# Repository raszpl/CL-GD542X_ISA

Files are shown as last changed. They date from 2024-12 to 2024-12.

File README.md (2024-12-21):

Fork of https://github.com/matt1187/542x_ISA 'Remaking from Cirrus Logic Databook "CL-GD542X_Technical_Reference_Manual_Jan1994"' attempting to show some routing optimizations.

# Results

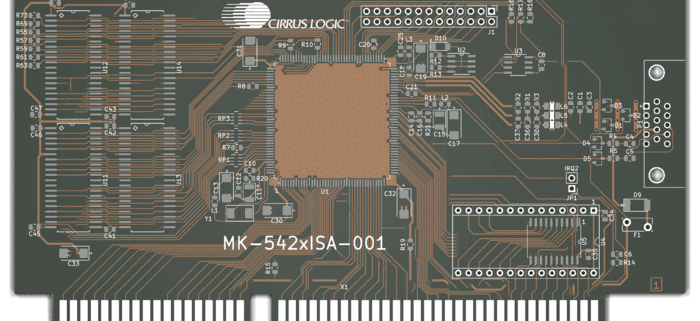
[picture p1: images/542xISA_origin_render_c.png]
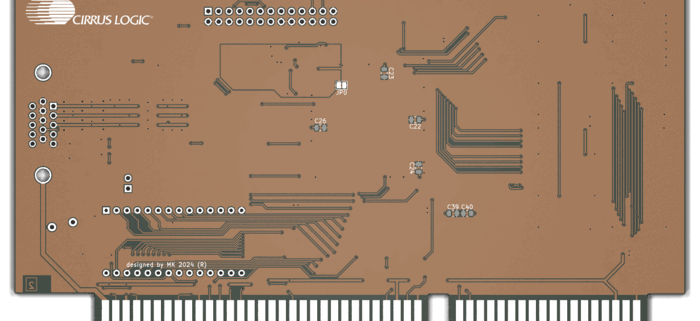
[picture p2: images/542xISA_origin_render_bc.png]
Original:[](/images/542xISA_origin_render.png?raw=true)[](/images/542xISA_origin_render_b.png?raw=true)

Optimisations, less and taking smaller area tracks you see on the back means better signal integrity.

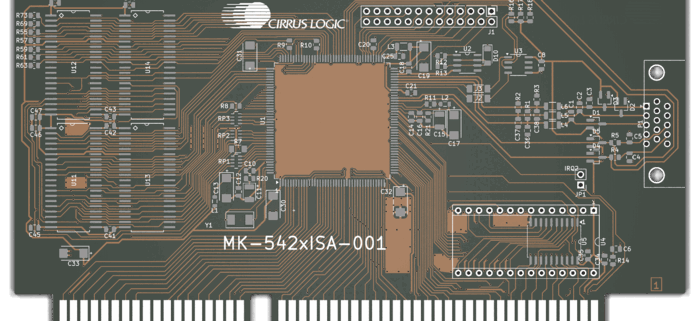
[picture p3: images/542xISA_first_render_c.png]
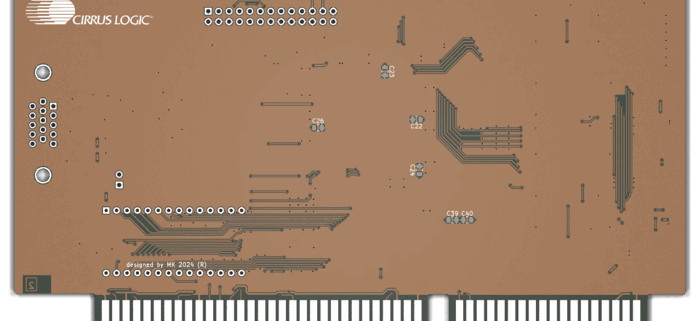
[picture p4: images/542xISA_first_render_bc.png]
Initial:[](/images/542xISA_first_render.png?raw=true)[](/images/542xISA_first_render_b.png?raw=true)

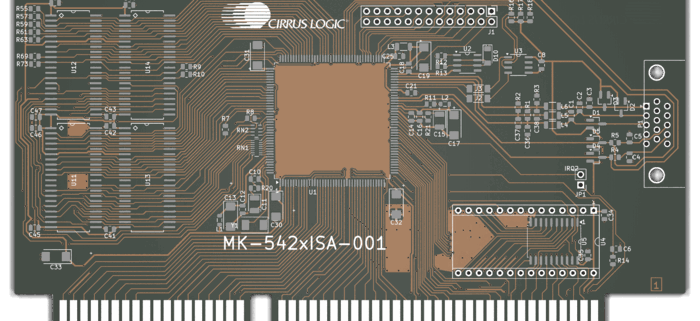
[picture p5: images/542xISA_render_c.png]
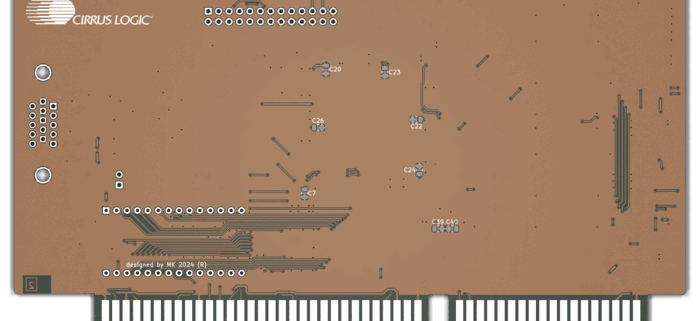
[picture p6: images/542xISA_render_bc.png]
Final:[](/images/542xISA_render.png?raw=true)[](/images/542xISA_render_b.png?raw=true)

Comparison between layouts: [Original](/images/original.png?raw=true), [Initial optimization](/images/first.png?raw=true), [Final version](/images/final.png?raw=true).

Black holes and red are cuts in ground plane, the smaller they are the better. Ideally you want one uninterrupted plane. Second bad but better than nothing option is ground island densely stitched on top of tracks forced to go into ground plane. Third bad option is as short as possible cuts to the ground plane and picking slow/steady (reset, VCC) signals as the ones going across, jumping across couple signals here and there is a lesser crime than slicing ground across half the PCB height. Fourth 'Im desperate here' option is crossing signals at 90 degree angle and hoping PCB thickness is enough. People in the eighties and early nineties didnt have it easy, nowadays similar size 4-layer PCBs are mere $20-30 for quick turnaround pototypes, with 6-layer not far behind at $40!

# Fixes

1 Bad ground. We dont want thin long ground noodles connected to real ground by a thin sliver on one side

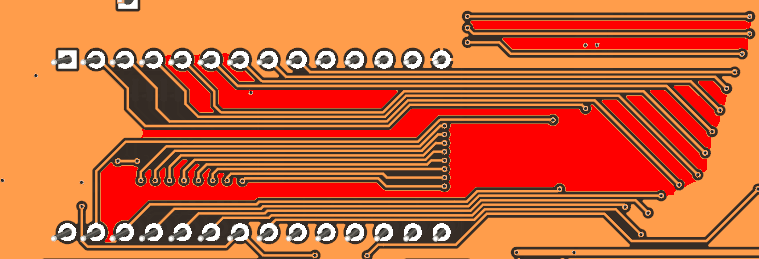
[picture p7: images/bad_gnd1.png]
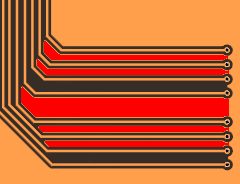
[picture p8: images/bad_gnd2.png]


like between:
- PD0 PD1 PD2 PD3 PD4 PD5 PD6
- PD16 20 21 22 23
- under U5
- tiny one under U11
- long big one under extended ISA slot
- A2_ISA 3 4 5 6 7

Ground that is not solid plane or densely (<wavelenght) stitched to solid plane no longer works as ground, it works like an antenna and amplifies interference. In the past guard traces were used before we had good modeling and understanding of magnetic propagation on the pcb, they only worked because putting one forced engineers to make more space between signal traces. All those dangling traces between signal tracks just resonate amplifying interference[^1].

3 Extended ISA slot - routing VCC straight to C33 instead of going across the card wouldnt be breaking ground plane under D8-16 and LA signals.

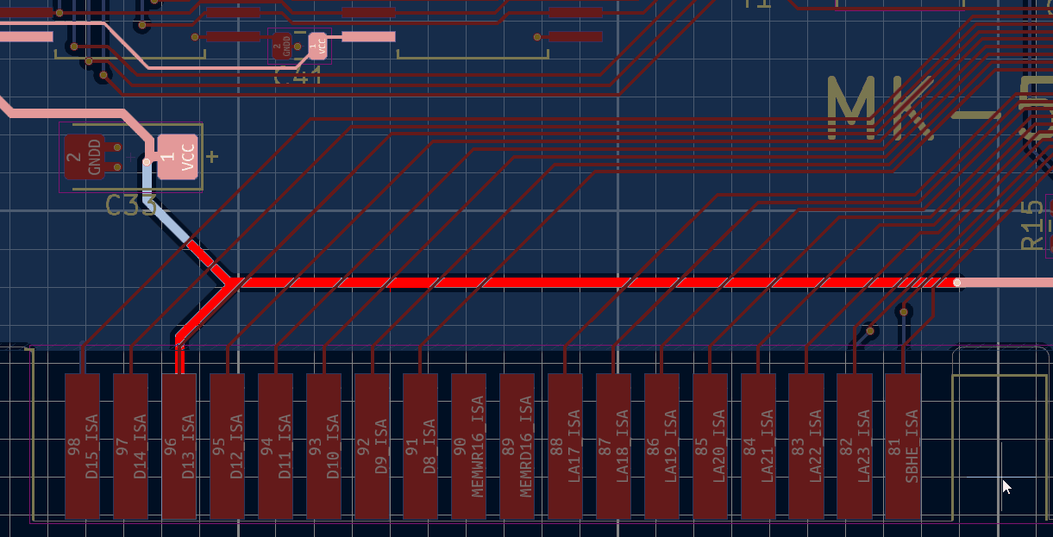
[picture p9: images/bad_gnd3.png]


4 Omitting ISA oscillator input option will make ground more solid. Currently it leaves a dangling track with very high frequency clock crossing D8-18 and LA lines while breaking ground even when unused. Using ISA 14MHz was a cost cutting measure saving maybe 50 cents for a crystal resonator and two capacitors in the nineties, nowadays useless.

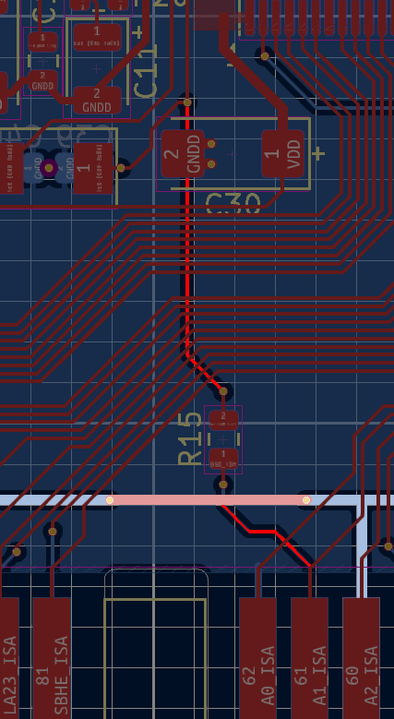
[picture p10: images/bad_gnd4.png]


5 Pin 159 oscillator goes in a weird around pad way making it go outside of ground plane coverage. Its especially critical to have uninterrupted ground under clock signals.

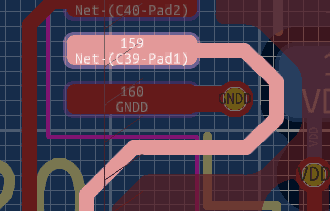
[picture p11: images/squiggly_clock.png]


6 Afaik separate isolated analog/digital ground planes is a relic of the past, modern techniques show it doesnt work if it cuts up ground into multiple islands and forces signals to cross them[^2][^3][^4]. Here for example it paradoxically messes with analog signal integrity by making RGB Video suddenly lose reference. Im fairly certain this aspect of Cirrus recommended design only makes things worse.

7 Optional EEprom pins also degrade analog RGB Video signals by breaking ground :( best option would be routing those two tracks with jumpers over analog RGB.

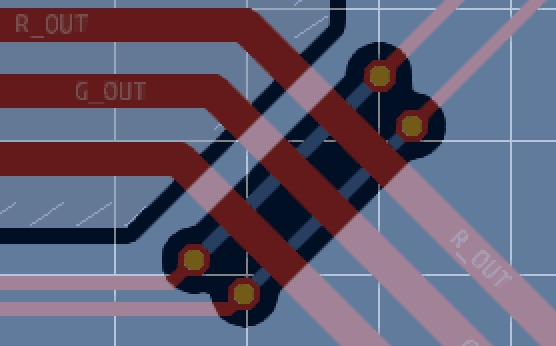
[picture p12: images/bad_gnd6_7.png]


8 Filtering analog VGA looks nice when symmetricaly placed in neat rows, but forces analog B crossing over analog G, and all analog tracks going under where they arent routed over ground plane. Vias high impedance is really bad for such high speed analog signals. Asymmetrical component placement might hurt OCD, but lets us leave Analog RGB on top layer over healthy uninterrupted ground.

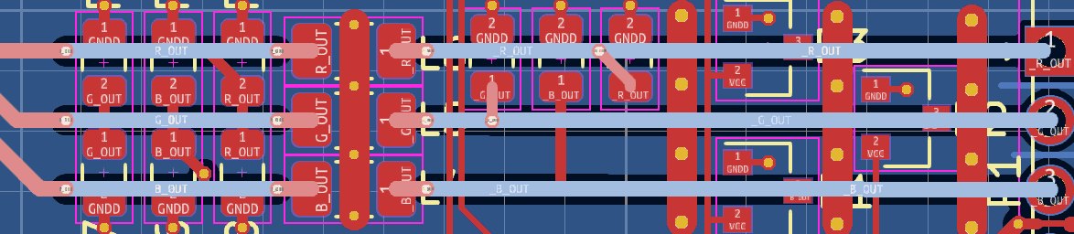
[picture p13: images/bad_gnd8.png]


9 H and V syncs cross each other with no ground underneath, swapping filtering sections around solves that.

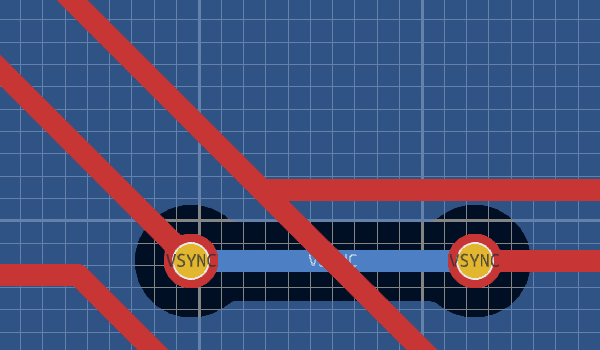
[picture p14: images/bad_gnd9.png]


10 3 amp fuse and thick tracks on Vga Pin 9 is overdoing it, especially considering Cirrus is not even capable of reading Edid. Removing altogether.

11 Very long RAS1 under U13 U14 can be avoided, makes it look stupid but ground plane is healthier = shorter cuts = shorter return paths = less interference and crosstalk.



TLDR Golden rule is every signal should run as close as possible (preferably over) a ground directly connecting source and destination of said signal with lowest impedance. Signals arent electrons, they are electromagnetic waves and need to close the loop. Closer the ground smaller the field, lower the ground impedance higher the frequency of mitigated interferences, bigger ground plane = better, traveling thru multiple vias = bad.

Some of the fixes are heavily overdoing it via stitched ground patches and are most likely also bad :) Nowadays upgrading from five PCBs with 2-layers to 4-layers of that size is $20, another $15 for 6-layer with ENIG finish, giving us infinitely healthier signal integrity and tons less routing work. __Please dont manufacture this!__ Other than for fun or experimentation there is very little sense manufacturing 2-layer design, repository is for educational purposes only.

# License
The project is free for non-commercial reproduction. Do not sell it on Ebay or other platforms for profit. Do not make a closed source derivative. Share your experiences and ideas with the community.

This work is licensed under a [Creative Commons Attribution-NonCommercial-ShareAlike 4.0 International License][cc-by-nc-sa].

[][cc-by-nc-sa]

[cc-by-nc-sa]: http://creativecommons.org/licenses/by-nc-sa/4.0/
[cc-by-nc-sa-image]: https://licensebuttons.net/l/by-nc-sa/4.0/88x31.png

# References
[^1]: https://resources.altium.com/p/guard-traces-hit-or-myth.
[^2]: https://resources.altium.com/p/how-to-use-a-star-point-for-analog-ground-digital-ground-connection
[^3]: https://resources.pcb.cadence.com/blog/2021-should-you-ever-separate-analog-and-digital-ground-planes
[^4]: "Ground planes in a PCB layout with 30 years of experience: The ultimate guide" by Hans Rosenberg https://www.youtube.com/watch?v=EEb_0dja8tE&list=PLsWHPs7La-3KUY2JDUyrz0Jc0xw8kH4zQ

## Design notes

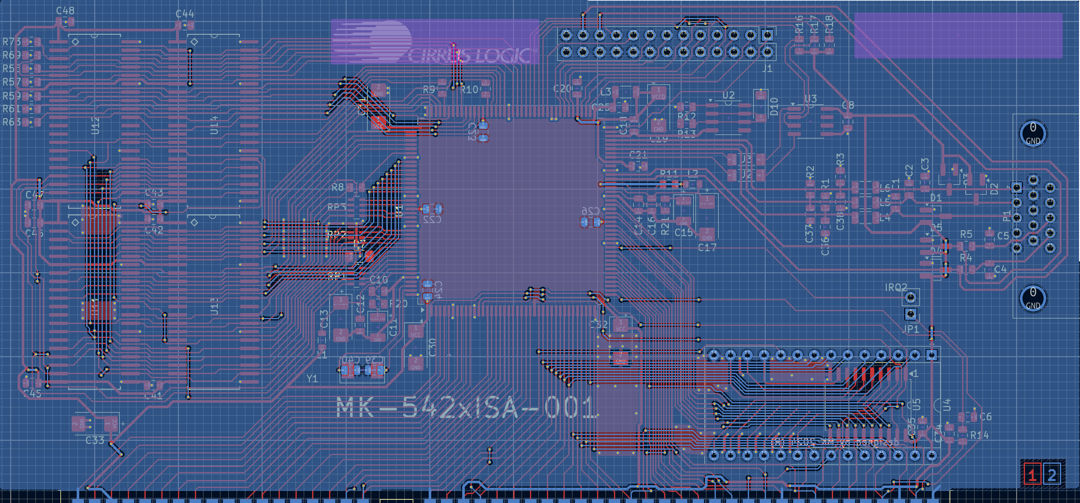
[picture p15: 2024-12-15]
images/first.png

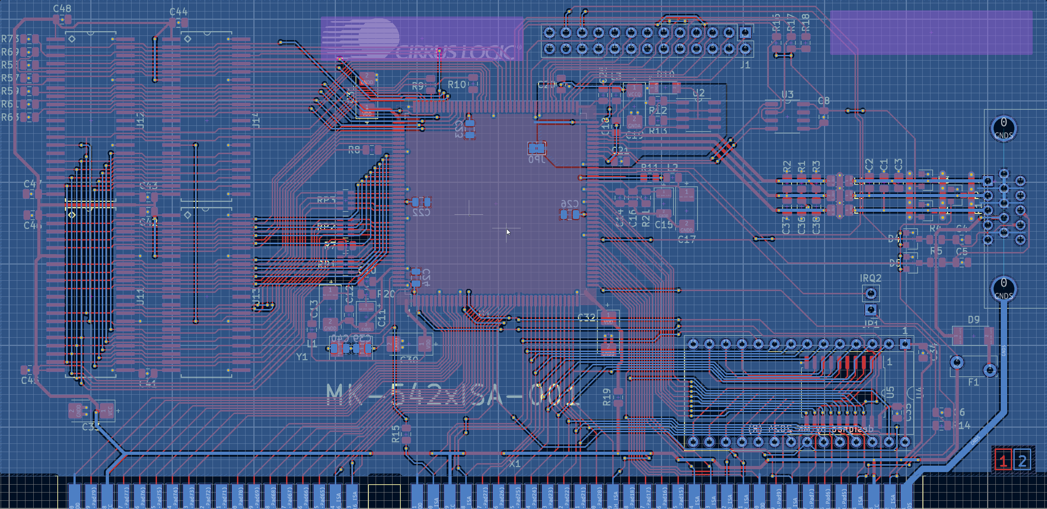
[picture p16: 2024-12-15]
images/original.png

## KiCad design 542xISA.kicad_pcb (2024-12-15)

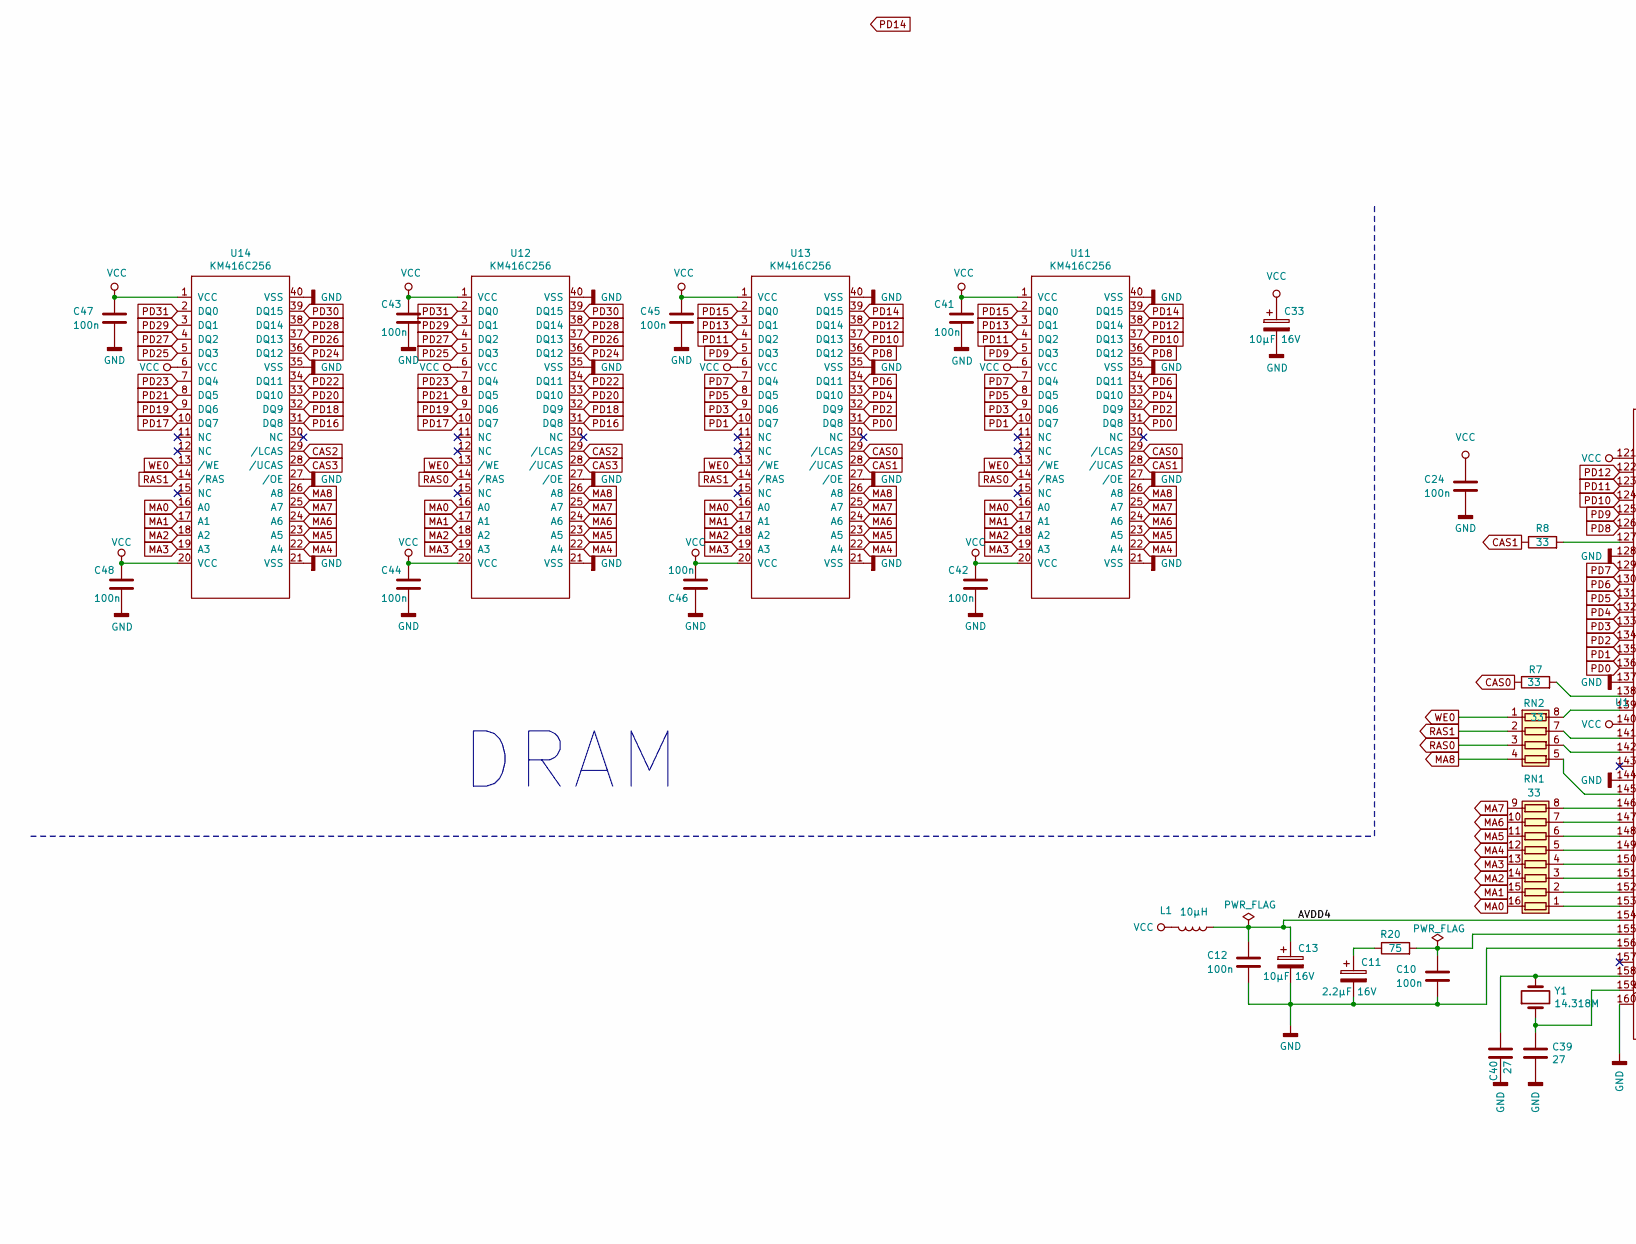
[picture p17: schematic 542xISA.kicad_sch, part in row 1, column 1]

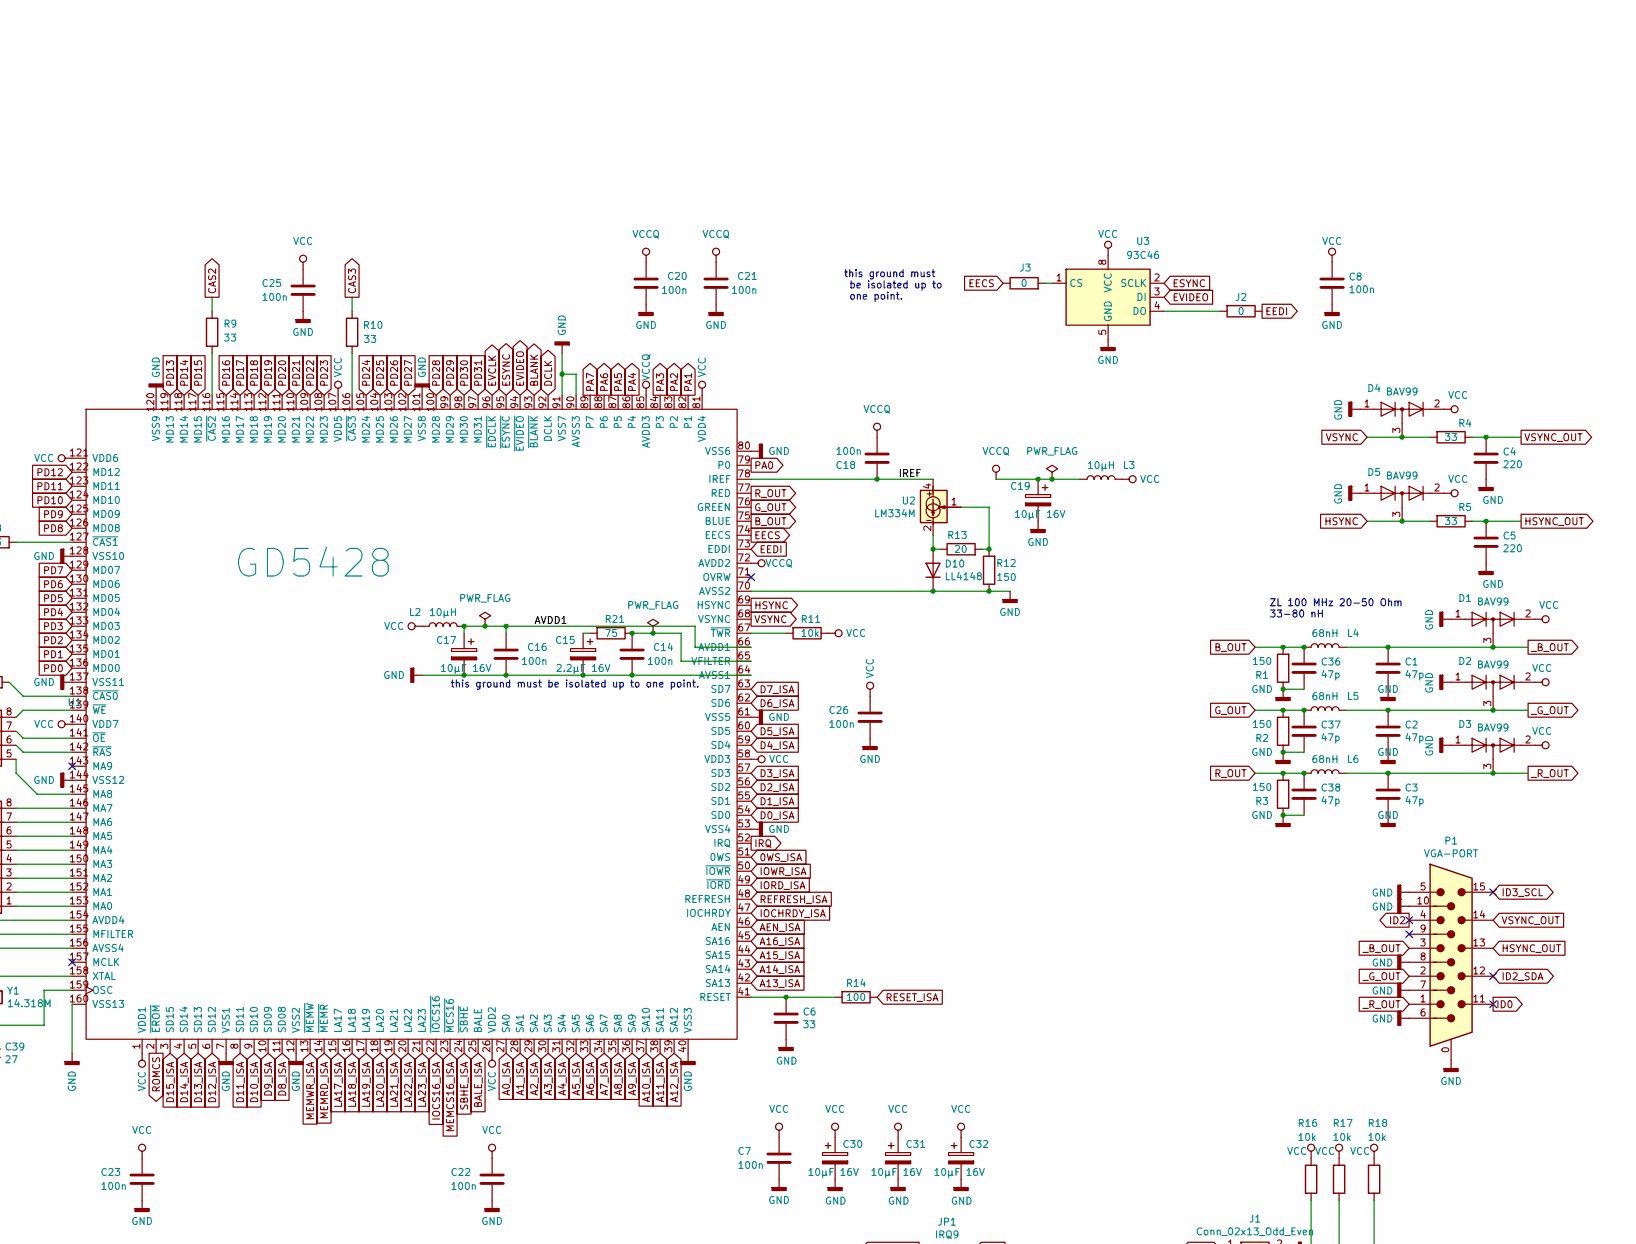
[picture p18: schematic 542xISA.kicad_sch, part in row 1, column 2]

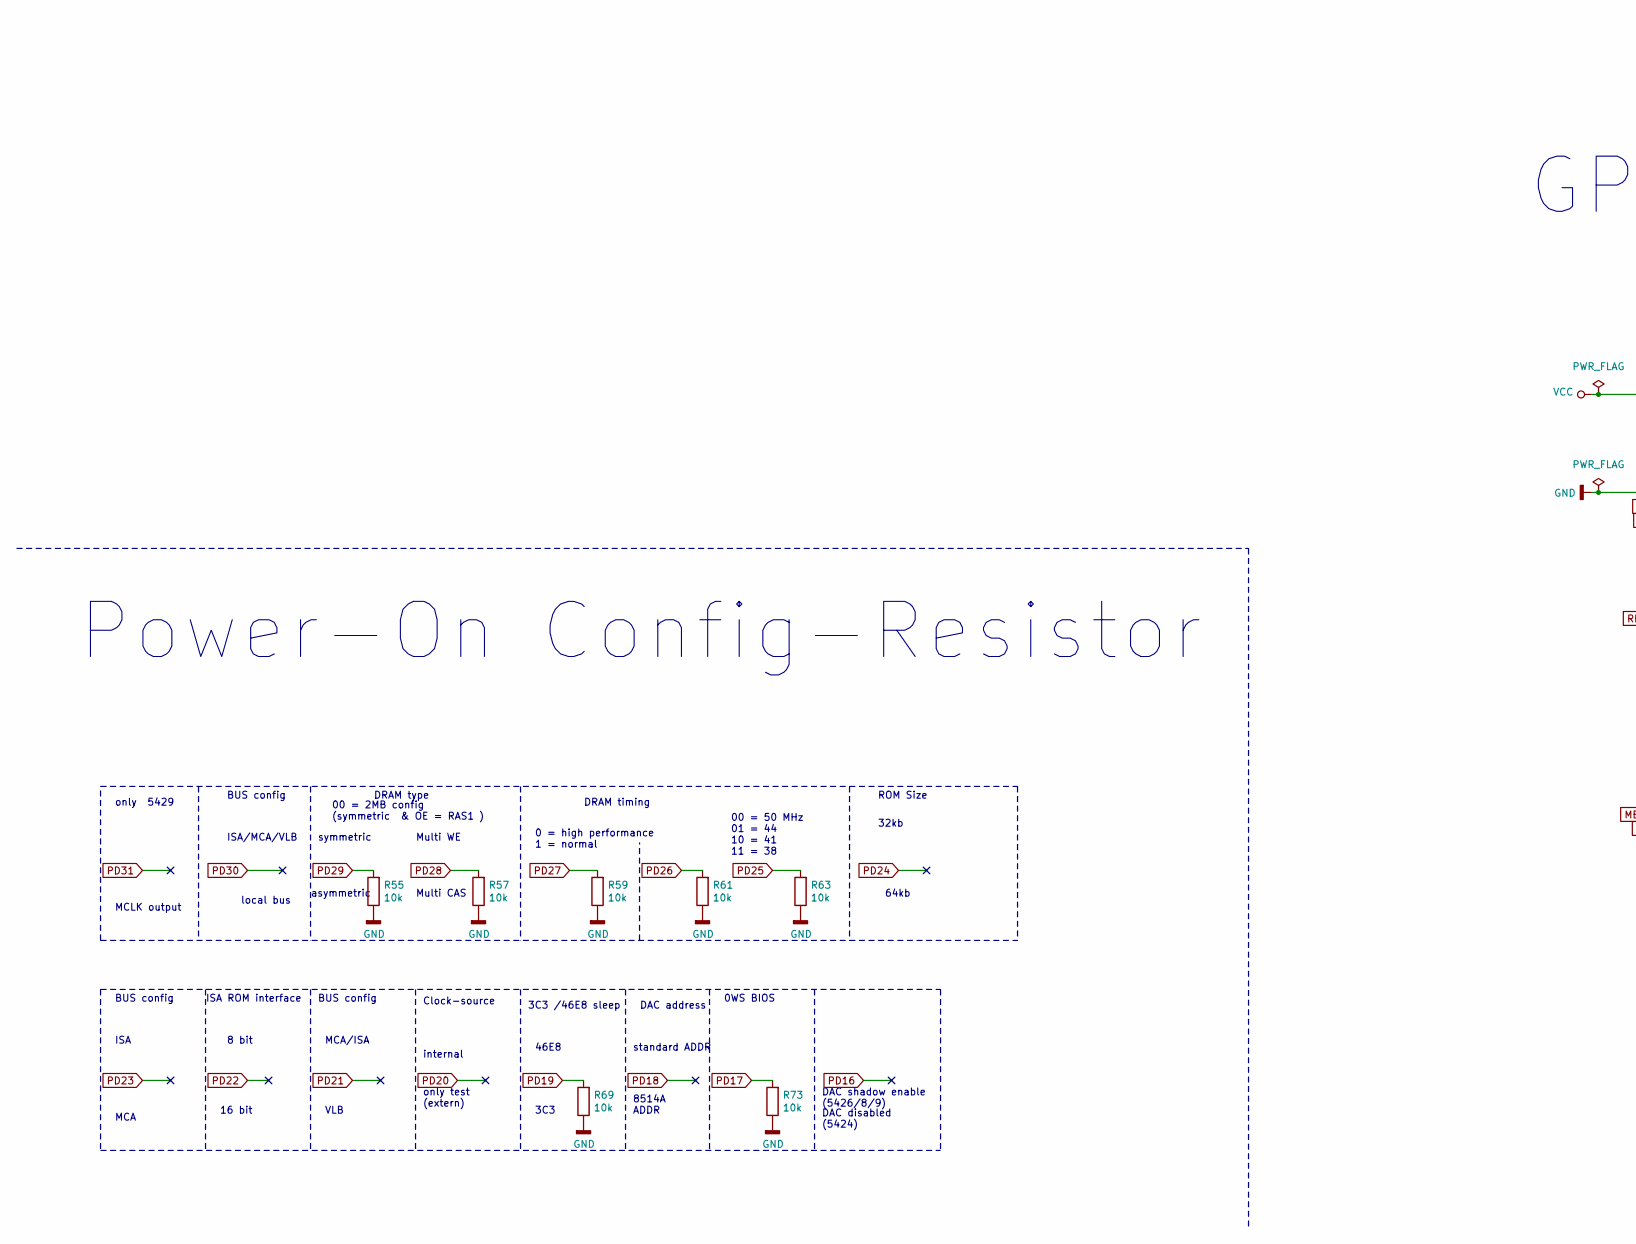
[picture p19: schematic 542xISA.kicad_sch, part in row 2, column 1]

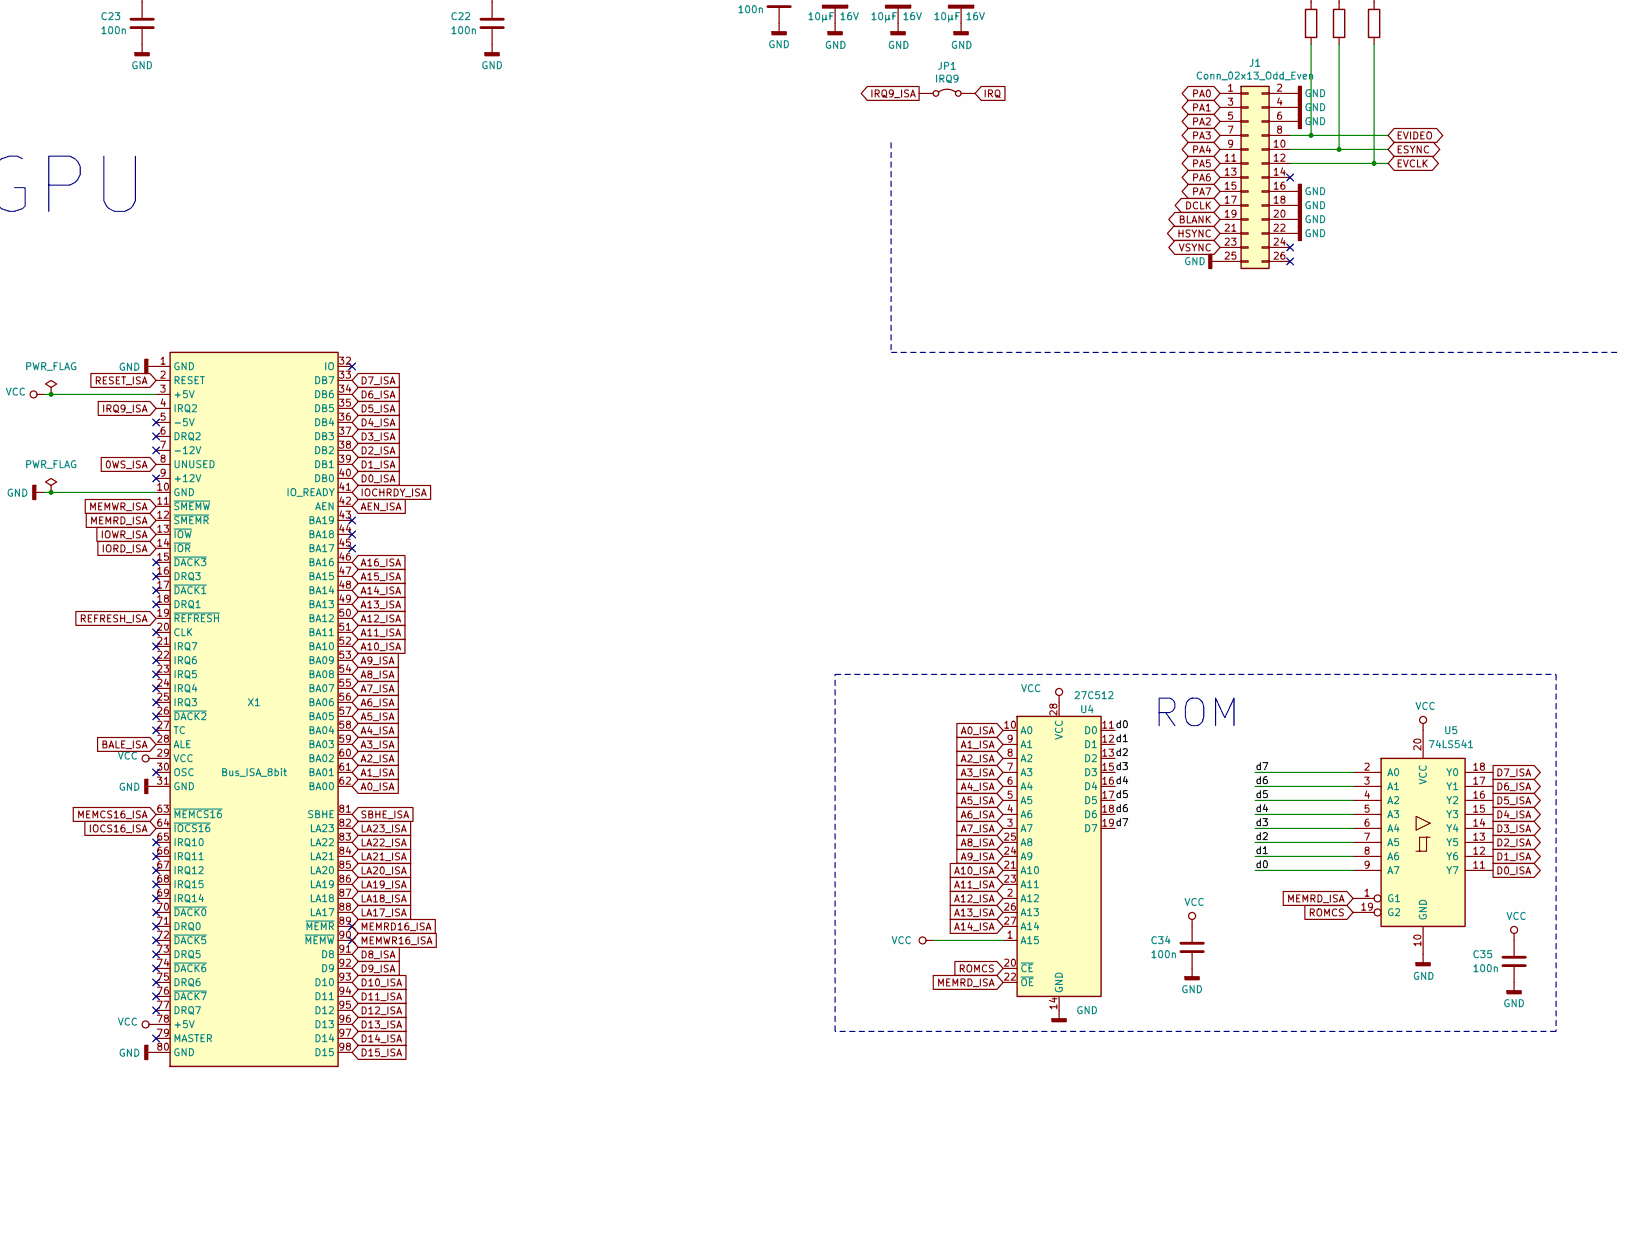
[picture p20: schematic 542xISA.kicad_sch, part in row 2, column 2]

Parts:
C1, C2, C3, C36, C37, C38: 47p; C_0805_2012Metric
C4, C5: 220; C_0805_2012Metric
C6: 33; C_0805_2012Metric
C7, C8, C10, C12, C14, C16, C18, C20, C21, C22, C23, C24, C25, C26, C34, C35, C41, C42, C43, C44, C45, C46, C47, C48: 100n; C_0805_2012Metric
C11, C15: 2.2µF 16V; CP_EIA-3528-12_Kemet-T
C13, C17, C19, C30, C31, C32, C33: 10µF 16V; CP_EIA-6032-15_Kemet-U
C39, C40: 27; C_0805_2012Metric
D1, D2, D3, D4, D5: BAV99; SOT-23_Handsoldering
D10: LL4148; D_MiniMELF
J1: Conn_02x13_Odd_Even; PinHeader_2x13_P2.54mm_Vertical
J2, J3: 0; L_1806_4516Metric_Pad1.45x1.90mm_HandSolder
JP1: IRQ9; PinHeader_1x02_P2.54mm_Vertical
L1, L2: 10µH; L_0805_2012Metric
L3: 10µH; L_1206_3216Metric
L4, L5, L6: 68nH; L_1206_3216Metric
P1: VGA-PORT; DSUB-15-HD_Female_Horizontal_P2.29x1.98mm_EdgePinOffset8.35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
R1, R2, R3, R12: 150; R_0805_2012Metric
R4, R5, R7, R8, R9, R10: 33; R_0805_2012Metric
R11, R16, R17, R18, R55, R57, R59, R61, R63, R69, R73: 10k; R_0805_2012Metric
R13: 20; R_0805_2012Metric
R14: 100; R_0805_2012Metric
R20, R21: 75; R_0805_2012Metric
RN1: 33; R_Array_Convex_8x0602
RN2: 33; R_Array_Concave_4x0603
U1: GD5428; PQFP-160_28x28mm_P0.65mm
U2: LM334M; SOIC-8_3.9x4.9mm_P1.27mm
U3: 93C46; SOIC-8_3.9x4.9mm_P1.27mm
U4: 27C512; DIP-28_W15.24mm_Socket
U5: 74LS541; SOIC-20W_7.5x12.8mm_P1.27mm
U11, U12, U13, U14: KM416C256; SOJ-40-Socket-LongPads
X1: Bus_ISA_8bit; BUS_AT
Y1: 14.318M; Crystal_SMD_0603-2Pin_6.0x3.5mm

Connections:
0WS_ISA: U1.51 (0WS), X1.8 (UNUSED)
/AVDD1: C16.1, C17.1, L2.2, U1.66 (AVDD1)
/AVDD4: C12.1, C13.1, L1.1, U1.154 (AVDD4)
/IREF: C18.1, U1.78 (IREF), U2.4
/d0: U4.11 (D0), U5.9 (A7)
/d1: U4.12 (D1), U5.8 (A6)
/d2: U4.13 (D2), U5.7 (A5)
/d3: U4.15 (D3), U5.6 (A4)
/d4: U4.16 (D4), U5.5 (A3)
/d5: U4.17 (D5), U5.4 (A2)
/d6: U4.18 (D6), U5.3 (A1)
/d7: U4.19 (D7), U5.2 (A0)
A0_ISA: U1.27 (SA0), U4.10 (A0), X1.62 (BA00)
A1_ISA: U1.28 (SA1), U4.9 (A1), X1.61 (BA01)
A2_ISA: U1.29 (SA2), U4.8 (A2), X1.60 (BA02)
A3_ISA: U1.30 (SA3), U4.7 (A3), X1.59 (BA03)
A4_ISA: U1.31 (SA4), U4.6 (A4), X1.58 (BA04)
A5_ISA: U1.32 (SA5), U4.5 (A5), X1.57 (BA05)
A6_ISA: U1.33 (SA6), U4.4 (A6), X1.56 (BA06)
A7_ISA: U1.34 (SA7), U4.3 (A7), X1.55 (BA07)
A8_ISA: U1.35 (SA8), U4.25 (A8), X1.54 (BA08)
A9_ISA: U1.36 (SA9), U4.24 (A9), X1.53 (BA09)
A10_ISA: U1.37 (SA10), U4.21 (A10), X1.52 (BA10)
A11_ISA: U1.38 (SA11), U4.23 (A11), X1.51 (BA11)
A12_ISA: U1.39 (SA12), U4.2 (A12), X1.50 (BA12)
A13_ISA: U1.42 (SA13), U4.26 (A13), X1.49 (BA13)
A14_ISA: U1.43 (SA14), U4.27 (A14), X1.48 (BA14)
A15_ISA: U1.44 (SA15), X1.47 (BA15)
A16_ISA: U1.45 (SA16), X1.46 (BA16)
AEN_ISA: U1.46 (AEN), X1.42 (AEN)
BALE_ISA: U1.25 (BALE), X1.28 (ALE)
BLANK: J1.19, U1.93 (~BLANK)
B_OUT: C36.1, L4.2, R1.2, U1.75 (BLUE)
CAS0: R7.1, U11.29 (/LCAS), U13.29 (/LCAS)
CAS1: R8.1, U11.28 (/UCAS), U13.28 (/UCAS)
CAS2: R9.1, U12.29 (/LCAS), U14.29 (/LCAS)
CAS3: R10.1, U12.28 (/UCAS), U14.28 (/UCAS)
D0_ISA: U1.54 (SD0), U5.11 (Y7), X1.40 (DB0)
D1_ISA: U1.55 (SD1), U5.12 (Y6), X1.39 (DB1)
D2_ISA: U1.56 (SD2), U5.13 (Y5), X1.38 (DB2)
D3_ISA: U1.57 (SD3), U5.14 (Y4), X1.37 (DB3)
D4_ISA: U1.59 (SD4), U5.15 (Y3), X1.36 (DB4)
D5_ISA: U1.60 (SD5), U5.16 (Y2), X1.35 (DB5)
D6_ISA: U1.62 (SD6), U5.17 (Y1), X1.34 (DB6)
D7_ISA: U1.63 (SD7), U5.18 (Y0), X1.33 (DB7)
D8_ISA: U1.11 (SD08), X1.91 (D8)
D9_ISA: U1.10 (SD09), X1.92 (D9)
D10_ISA: U1.9 (SD10), X1.93 (D10)
D11_ISA: U1.8 (SD11), X1.94 (D11)
D12_ISA: U1.6 (SD12), X1.95 (D12)
D13_ISA: U1.5 (SD13), X1.96 (D13)
D14_ISA: U1.4 (SD14), X1.97 (D14)
D15_ISA: U1.3 (SD15), X1.98 (D15)
DCLK: J1.17, U1.92 (DCLK)
EECS: J3.1, U1.74 (EECS)
EEDI: J2.1, U1.73 (EDDI)
ESYNC: J1.10, R17.2, U1.95 (~ESYNC), U3.2 (SCLK)
EVCLK: J1.12, R18.2, U1.96 (~EDCLK)
EVIDEO: J1.8, R16.2, U1.94 (~EVIDEO), U3.3 (DI)
GND: C1.2, C2.2, C3.2, C4.2, C5.2, C6.2, C7.2, C8.2, C10.2, C11.2, C12.2, C13.2, C14.2, C15.2, C16.2, C17.2, C19.2, C20.2, C21.2, C22.2, C23.2, C24.2, C25.2, C26.2, C30.2, C31.2, C32.2, C33.2, C34.2, C35.2, C36.2, C37.2, C38.2, C39.2, C40.1, C41.2, C42.2, C43.2, C44.2, C45.2, C46.2, C47.2, C48.2, D1.1 (K), D2.1 (K), D3.1 (K), D4.1 (K), D5.1 (K), D10.1 (K), J1.2, J1.4, J1.6, J1.16, J1.18, J1.20, J1.22, J1.25, P1.0, P1.5, P1.6, P1.7, P1.8, P1.10, R1.1, R2.1, R3.1, R12.1, R55.1, R57.1, R59.1, R61.1, R63.1, R69.1, R73.1, U1.7 (VSS1), U1.12 (VSS2), U1.40 (VSS3), U1.53 (VSS4), U1.61 (VSS5), U1.64 (AVSS1), U1.70 (AVSS2), U1.80 (VSS6), U1.90 (AVSS3), U1.91 (VSS7), U1.101 (VSS8), U1.120 (VSS9), U1.128 (VSS10), U1.137 (VSS11), U1.144 (VSS12), U1.156 (AVSS4), U1.160 (VSS13), U3.5 (GND), U4.14 (GND), U5.10 (GND), U11.21 (VSS), U11.27 (/OE), U11.35 (VSS), U11.40 (VSS), U12.21 (VSS), U12.27 (/OE), U12.35 (VSS), U12.40 (VSS), U13.21 (VSS), U13.27 (/OE), U13.35 (VSS), U13.40 (VSS), U14.21 (VSS), U14.27 (/OE), U14.35 (VSS), U14.40 (VSS), X1.1 (GND), X1.10 (GND), X1.31 (GND), X1.80 (GND)
G_OUT: C37.1, L5.2, R2.2, U1.76 (GREEN)
HSYNC: D5.3 (K), J1.21, R5.2, U1.69 (HSYNC)
HSYNC_OUT: C5.1, P1.13, R5.1
ID0: P1.11
ID2: P1.4
ID2_SDA: P1.12
ID3_SCL: P1.15
IOCHRDY_ISA: U1.47 (IOCHRDY), X1.41 (IO_READY)
IOCS16_ISA: U1.22 (~IOCS16), X1.64 (~IOCS16)
IORD_ISA: U1.49 (~IORD), X1.14 (~IOR)
IOWR_ISA: U1.50 (~IOWR), X1.13 (~IOW)
IRQ: JP1.2 (B), U1.52 (IRQ)
IRQ9_ISA: JP1.1 (A), X1.4 (IRQ2)
LA17_ISA: U1.15 (LA17), X1.88 (LA17)
LA18_ISA: U1.16 (LA18), X1.87 (LA18)
LA19_ISA: U1.17 (LA19), X1.86 (LA19)
LA20_ISA: U1.18 (LA20), X1.85 (LA20)
LA21_ISA: U1.19 (LA21), X1.84 (LA21)
LA22_ISA: U1.20 (LA22), X1.83 (LA22)
LA23_ISA: U1.21 (LA23), X1.82 (LA23)
MA0: RN1.16 (R1.2), U11.16 (A0), U12.16 (A0), U13.16 (A0), U14.16 (A0)
MA1: RN1.15 (R2.2), U11.17 (A1), U12.17 (A1), U13.17 (A1), U14.17 (A1)
MA2: RN1.14 (R3.2), U11.18 (A2), U12.18 (A2), U13.18 (A2), U14.18 (A2)
MA3: RN1.13 (R4.2), U11.19 (A3), U12.19 (A3), U13.19 (A3), U14.19 (A3)
MA4: RN1.12 (R5.2), U11.22 (A4), U12.22 (A4), U13.22 (A4), U14.22 (A4)
MA5: RN1.11 (R6.2), U11.23 (A5), U12.23 (A5), U13.23 (A5), U14.23 (A5)
MA6: RN1.10 (R7.2), U11.24 (A6), U12.24 (A6), U13.24 (A6), U14.24 (A6)
MA7: RN1.9 (R8.2), U11.25 (A7), U12.25 (A7), U13.25 (A7), U14.25 (A7)
MA8: RN2.4 (R4.1), U11.26 (A8), U12.26 (A8), U13.26 (A8), U14.26 (A8)
MEMCS16_ISA: U1.23 (~MCS16), X1.63 (~MEMCS16)
MEMRD16_ISA: X1.89 (~MEMR)
MEMRD_ISA: U1.14 (~MEMR), U4.22 (~OE), U5.1 (G1), X1.12 (~SMEMR)
MEMWR16_ISA: X1.90 (~MEMW)
MEMWR_ISA: U1.13 (~MEMW), X1.11 (~SMEMW)
unnamed: C11.1, R20.1
unnamed: C15.1, R21.2
unnamed: D10.2 (A), R13.1, U2.2, U2.3, U2.6, U2.7
unnamed: R12.2, R13.2, U2.1
unnamed: RN1.1 (R1.1), U1.153 (MA0)
unnamed: RN1.2 (R2.1), U1.152 (MA1)
unnamed: RN1.3 (R3.1), U1.151 (MA2)
unnamed: RN1.4 (R4.1), U1.150 (MA3)
unnamed: RN1.5 (R5.1), U1.149 (MA4)
unnamed: RN1.6 (R6.1), U1.148 (MA5)
unnamed: RN1.7 (R7.1), U1.147 (MA6)
unnamed: RN1.8 (R8.1), U1.146 (MA7)
unnamed: RN2.8 (R1.2), U1.139 (~WE)
unnamed: RN2.7 (R2.2), U1.141 (~OE)
unnamed: RN2.6 (R3.2), U1.142 (~RAS)
unnamed: RN2.5 (R4.2), U1.145 (MA8)
unnamed: C10.1, R20.2, U1.155 (MFILTER)
unnamed: C39.1, U1.159 (OSC), Y1.1
unnamed: C6.1, R14.2, U1.41 (RESET)
unnamed: C14.1, R21.1, U1.65 (VFILTER)
unnamed: C40.2, U1.158 (XTAL), Y1.2
unnamed: R7.2, U1.138 (~CAS0)
unnamed: R8.2, U1.127 (~CAS1)
unnamed: R9.2, U1.116 (~CAS2)
unnamed: R10.2, U1.106 (~CAS3)
unnamed: R11.2, U1.67 (~TWR)
unnamed: J3.2, U3.1 (CS)
unnamed: J2.2, U3.4 (DO)
PA0: J1.1, U1.79 (P0)
PA1: J1.3, U1.82 (P1)
PA2: J1.5, U1.83 (P2)
PA3: J1.7, U1.84 (P3)
PA4: J1.9, U1.86 (P4)
PA5: J1.11, U1.87 (P5)
PA6: J1.13, U1.88 (P6)
PA7: J1.15, U1.89 (P7)
PD0: U1.136 (MD00), U11.31 (DQ8), U13.31 (DQ8)
PD1: U1.135 (MD01), U11.10 (DQ7), U13.10 (DQ7)
PD2: U1.134 (MD02), U11.32 (DQ9), U13.32 (DQ9)
PD3: U1.133 (MD03), U11.9 (DQ6), U13.9 (DQ6)
PD4: U1.132 (MD04), U11.33 (DQ10), U13.33 (DQ10)
PD5: U1.131 (MD05), U11.8 (DQ5), U13.8 (DQ5)
PD6: U1.130 (MD06), U11.34 (DQ11), U13.34 (DQ11)
PD7: U1.129 (MD07), U11.7 (DQ4), U13.7 (DQ4)
PD8: U1.126 (MD08), U11.36 (DQ12), U13.36 (DQ12)
PD9: U1.125 (MD09), U11.5 (DQ3), U13.5 (DQ3)
PD10: U1.124 (MD10), U11.37 (DQ13), U13.37 (DQ13)
PD11: U1.123 (MD11), U11.4 (DQ2), U13.4 (DQ2)
PD12: U1.122 (MD12), U11.38 (DQ14), U13.38 (DQ14)
PD13: U1.119 (MD13), U11.3 (DQ1), U13.3 (DQ1)
PD14: U1.118 (MD14), U11.39 (DQ15), U13.39 (DQ15)
PD15: U1.117 (MD15), U11.2 (DQ0), U13.2 (DQ0)
PD16: U1.115 (MD16), U12.31 (DQ8), U14.31 (DQ8)
PD17: R73.2, U1.114 (MD17), U12.10 (DQ7), U14.10 (DQ7)
PD18: U1.113 (MD18), U12.32 (DQ9), U14.32 (DQ9)
PD19: R69.2, U1.112 (MD19), U12.9 (DQ6), U14.9 (DQ6)
PD20: U1.111 (MD20), U12.33 (DQ10), U14.33 (DQ10)
PD21: U1.110 (MD21), U12.8 (DQ5), U14.8 (DQ5)
PD22: U1.109 (MD22), U12.34 (DQ11), U14.34 (DQ11)
PD23: U1.108 (MD23), U12.7 (DQ4), U14.7 (DQ4)
PD24: U1.105 (MD24), U12.36 (DQ12), U14.36 (DQ12)
PD25: R63.2, U1.104 (MD25), U12.5 (DQ3), U14.5 (DQ3)
PD26: R61.2, U1.103 (MD26), U12.37 (DQ13), U14.37 (DQ13)
PD27: R59.2, U1.102 (MD27), U12.4 (DQ2), U14.4 (DQ2)
PD28: R57.2, U1.100 (MD28), U12.38 (DQ14), U14.38 (DQ14)
PD29: R55.2, U1.99 (MD29), U12.3 (DQ1), U14.3 (DQ1)
PD30: U1.98 (MD30), U12.39 (DQ15), U14.39 (DQ15)
PD31: U1.97 (MD31), U12.2 (DQ0), U14.2 (DQ0)
RAS0: RN2.3 (R3.1), U11.14 (/RAS), U12.14 (/RAS)
RAS1: RN2.2 (R2.1), U13.14 (/RAS), U14.14 (/RAS)
REFRESH_ISA: U1.48 (REFRESH), X1.19 (~REFRESH)
RESET_ISA: R14.1, X1.2 (RESET)
ROMCS: U1.2 (~EROM), U4.20 (~CE), U5.19 (G2)
R_OUT: C38.1, L6.2, R3.2, U1.77 (RED)
SBHE_ISA: U1.24 (~SBHE), X1.81 (SBHE)
VCC: C7.1, C8.1, C22.1, C23.1, C24.1, C25.1, C26.1, C30.1, C31.1, C32.1, C33.1, C34.1, C35.1, C41.1, C42.1, C43.1, C44.1, C45.1, C46.1, C47.1, C48.1, D1.2 (A), D2.2 (A), D3.2 (A), D4.2 (A), D5.2 (A), L1.2, L2.1, L3.1, R11.1, R16.1, R17.1, R18.1, U1.1 (VDD1), U1.26 (VDD2), U1.58 (VDD3), U1.81 (VDD4), U1.107 (VDD5), U1.121 (VDD6), U1.140 (VDD7), U3.8 (VCC), U4.1 (A15), U4.28 (VCC), U5.20 (VCC), U11.1 (VCC), U11.6 (VCC), U11.20 (VCC), U12.1 (VCC), U12.6 (VCC), U12.20 (VCC), U13.1 (VCC), U13.6 (VCC), U13.20 (VCC), U14.1 (VCC), U14.6 (VCC), U14.20 (VCC), X1.3 (+5V), X1.29 (VCC), X1.78 (+5V)
VCCQ: C18.2, C19.1, C20.1, C21.1, L3.2, U1.72 (AVDD2), U1.85 (AVDD3)
VSYNC: D4.3 (K), J1.23, R4.2, U1.68 (VSYNC)
VSYNC_OUT: C4.1, P1.14, R4.1
WE0: RN2.1 (R1.1), U11.13 (/WE), U12.13 (/WE), U13.13 (/WE), U14.13 (/WE)
_B_OUT: C1.1, D1.3 (K), L4.1, P1.3
_G_OUT: C2.1, D2.3 (K), L5.1, P1.2
_R_OUT: C3.1, D3.3 (K), L6.1, P1.1

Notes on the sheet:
standard ADDR
DAC disabled (5424)
8 bit
DRAM
ISA/MCA/VLB
8514A ADDR
VLB
00 = 50 MHz 01 = 44 10 = 41 11 = 38
BUS config
MCLK output
Multi CAS
16 bit
MCA/ISA
32kb
Clock-source
ISA
GPU
DRAM timing
symmetric
only test (extern)
DAC address
Power-On Config-Resistor
this ground must be isolated up to one point.
64kb
3C3 /46E8 sleep
46E8
MCA
DAC shadow enable (5426/8/9)
only 5429
00 = 2MB config (symmetric & OE = RAS1 )
DRAM type
this ground must be isolated up to one point.
ROM
local bus
ZL 100 MHz 20-50 Ohm 33-80 nH
3C3
asymmetric
Multi WE
ISA ROM interface
0 = high performance 1 = normal

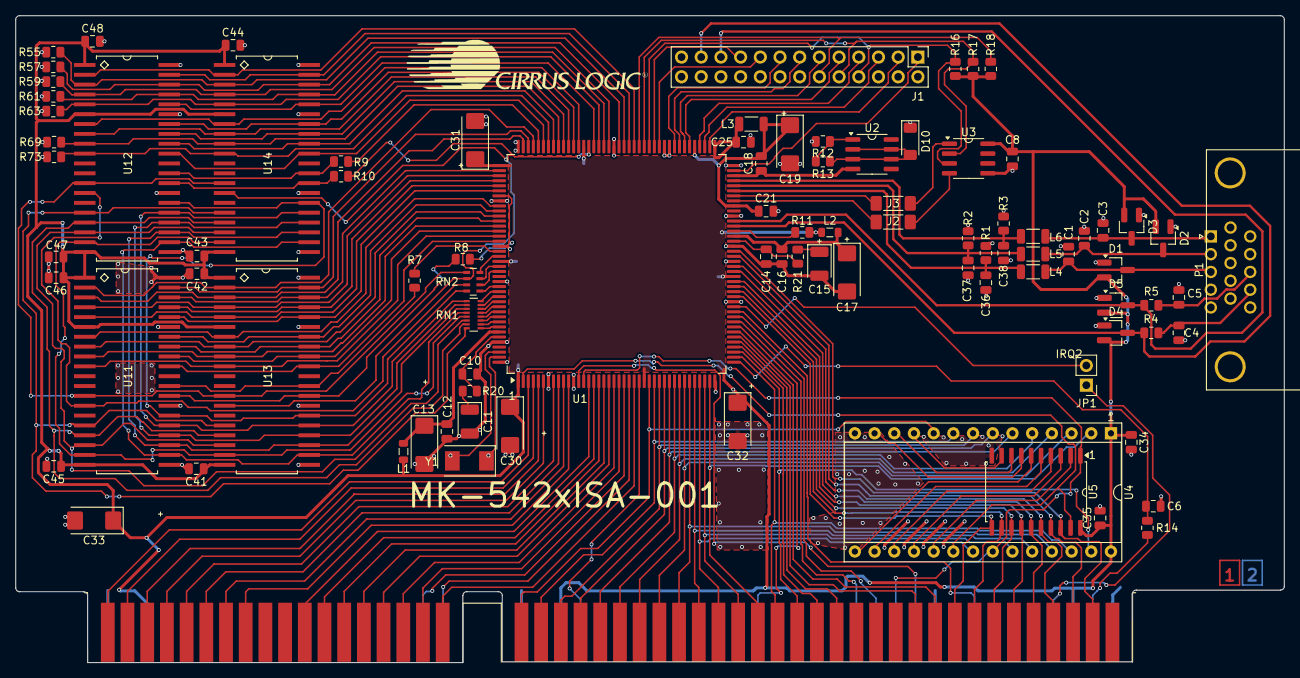
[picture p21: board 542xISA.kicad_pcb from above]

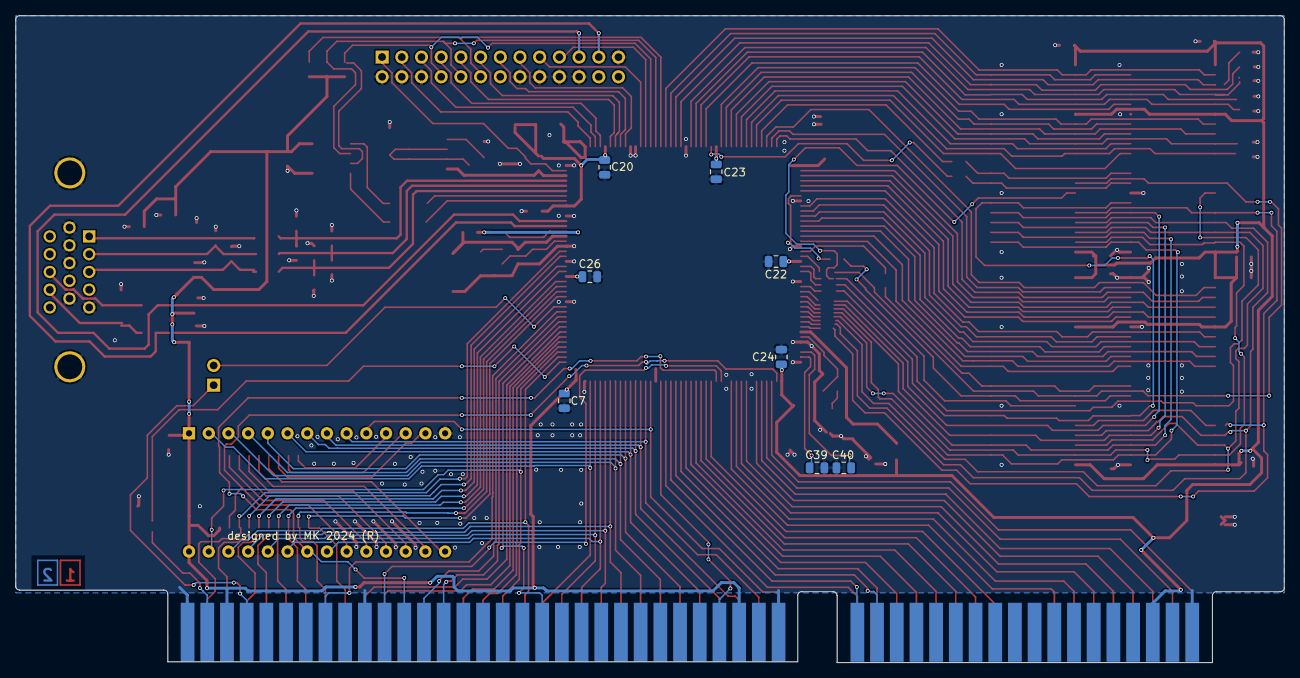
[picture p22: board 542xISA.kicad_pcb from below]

Board: 2 copper layers, 163.6 x 83.4 mm, 99 parts (8 on the bottom side), 171 nets.

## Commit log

2024-12-14 0 ERC, 0 DRC errors.
    [542xISA.kicad_pcb, 542xISA.kicad_sch]
2024-12-15 final version
    [542xISA.kicad_pcb, 542xISA.kicad_sch]
